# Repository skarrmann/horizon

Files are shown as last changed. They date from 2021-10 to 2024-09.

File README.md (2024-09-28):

# Horizon Keyboard

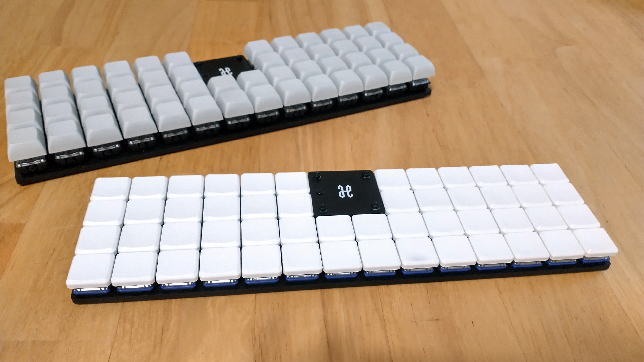
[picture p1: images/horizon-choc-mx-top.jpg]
Horizon Choc + MX complete build top photo


Horizon is a 52 key (4x14) ortholinear keyboard, powered by an Arduino Pro Micro.

This keyboard is a grid of 1U keys with no special features: no hotswap, no RGB, no OLED screen, no knobs.

## Project structure

* [`gerbers`](gerbers): Gerber files for PCB manufacturing
* [`graphics`](graphics): Source assets for PCB silkscreen
* [`kicad`](kicad): KiCad project files (schematics and PCB designs)
* [`kicad-libraries`](kicad-libraries): KiCad components and footprints
* [`kicad-plugins`](kicad-plugins): KiCad Pcbnew Python plugins
* [`images`](images): Images for project documentation

## PCBs

Two separate PCB designs are available for MX and Choc keyswitches, with their respective footprints and key spacing (MX: 19mm x 19mm, Choc: 18mm x 17mm).

Each design consists of a main PCB, a top plate to protect the microcontroller, and a bottom plate to protect the bottom components:

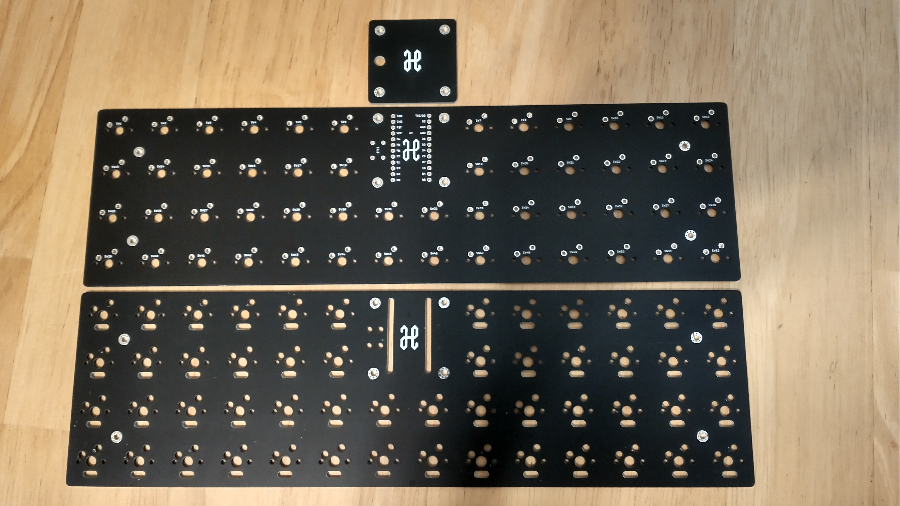
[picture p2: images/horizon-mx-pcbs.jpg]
Horizon MX PCBs photo


The bottom plate is a cutout of all the components exposed through the bottom of the main PCB, and screws *directly* against the main PCB. This nicely guards you and your desk surface from all the pointy through-hole bits, while retaining a low keyboard height:

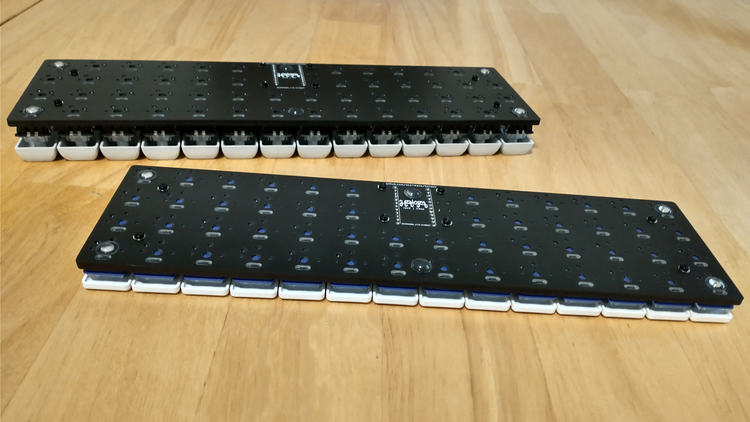
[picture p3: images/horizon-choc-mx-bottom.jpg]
Horizon Choc + MX complete build bottom photo


## KiCad project notes

The bottom and top plates are generated via a custom KiCad 7 Python SWIG plugin [Horizon Board Producer](kicad-plugins/horizon-board-producer-plugin.py).

For the plugin to generate these plate boards, the PCB and its footprints use the following layer convention:

* `F.Adhesive` designates top plate holes and edge cuts.
* `B.Adhesive` designates bottom plate holes and edge cuts.

When the board producer runs, these layers are used as follows:

* On the board and footprints:
    * Graphics on the plate's designated layer will be moved to `Edge.Cuts` when producing that plate.
    * As with all edge cuts, please make sure your graphics are non-overlapping closed shapes.
* On footprints only:
    * Pads of type "SMD Aperture" and shape "Circular/Oval" on the plate's designated layer will be converted to proper NPTH pads.
    * Note only circular/oval shapes are supported for these pads, because they are the only available hole/drill shapes. If you need a fancy plate cutout shape on your footprint, then draw graphics lines on the designated layer.
    * **IMPORTANT**: When adding pads solely for plate cutout purposes, set the technical layer to just the designated plate cutout layers. Leave all other technical layers unchecked.

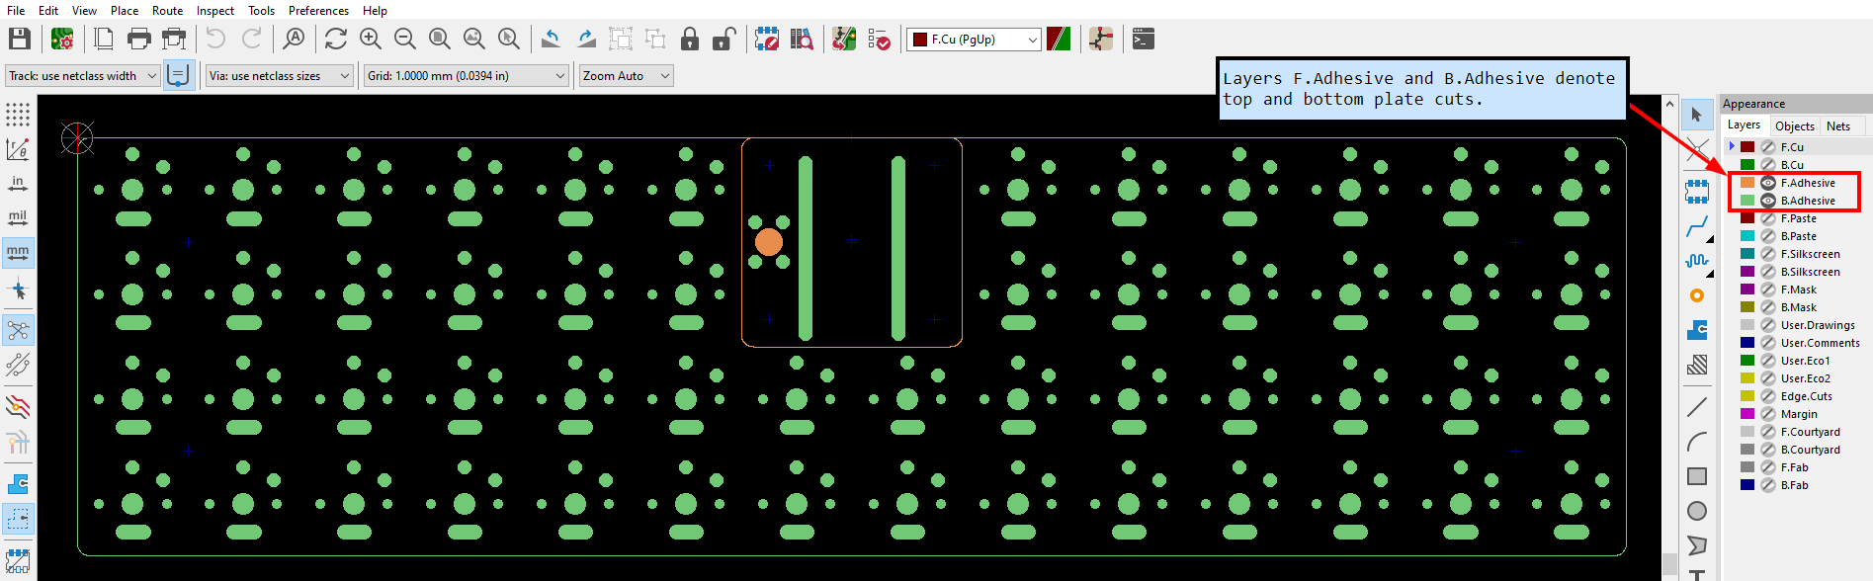
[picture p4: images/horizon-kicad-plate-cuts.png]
Horizon KiCad plate edge cuts

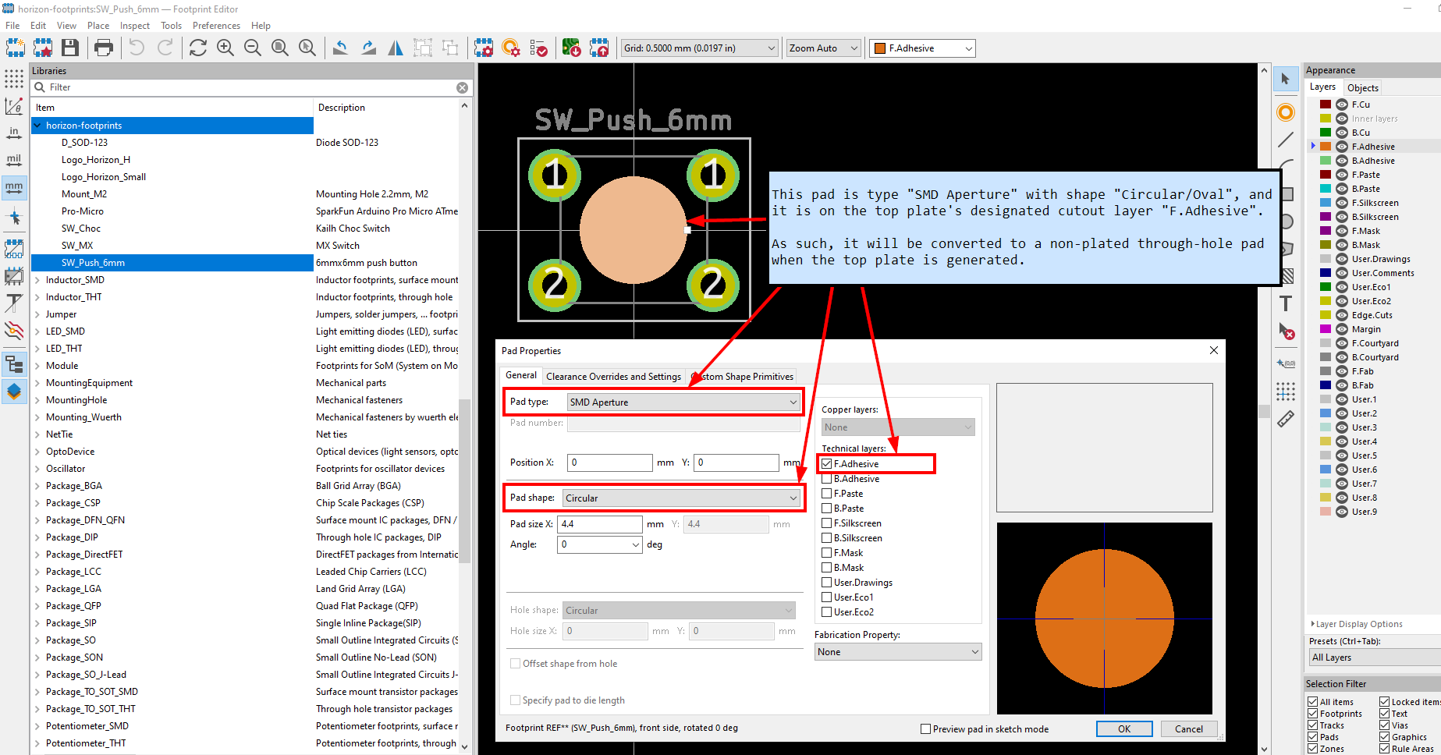
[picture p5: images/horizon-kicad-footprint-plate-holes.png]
Horizon KiCad footprint plate holes


Additionally, the board producer plugin will preserve any in-bounds "H" footprint pads (mounting holes), "LOGO" footprint graphics (custom silkscreen art), and board silkscreen on the plates. Other items which are not needed for plates (e.g., copper tracks and zones) are removed from the plates.

The board producer plugin also generates all the Gerber files for production.

Please note the board producer plugin expects the following folder structure:

* The KiCad PCB file is two folders deep from the project root, e.g., `kicad/[board-version]/[board-name].kicad_pcb`
* When the plugin executes, a folder called `temp` is created in the project root to store any temporary files created.
    * Each time the board producer runs, any existing files in this temporary folder are deleted.

**IMPORTANT:** If you would like to use this plugin and plate edge cuts convention for you own project, please make sure you carefully examine the output Gerber files! The plugin ultimately worked well for my case, but you might need to make adjustments to the plugin to suit your project. And to reduce the chance of being charged extra money by PCB manufacturers, use footprint plate holes instead of edge cuts whenever reasonable to do so.

**IMPORTANT:** This plugin uses `pcbnew.LoadBoard()` to load copies of the PCB, which is [not safely supported in a running instance of KiCad](https://forum.kicad.info/t/the-loadboard-function-is-invalid/31238/9). To avoid project integrity problems this may cause to the running KiCad instance, the plugin forcefully exits KiCad upon execution completion.

## Keyboard firmware

* [QMK](https://github.com/qmk/qmk_firmware/tree/master/keyboards/horizon)
* ZMK
    * Horizon shield definition is in [skarrmann's zmk-config](https://github.com/skarrmann/zmk-config)

## Bill of materials

For PCBs, keyswitches, and keycaps, get parts depending on your desired keyswitch type.

Part | Purpose | Quantity | Notes
---- | ------- | -------- | ---------
Main PCB  | circuit board | 1 | Send Gerber zip files to [JLCPCB](https://jlcpcb.com/).
Top plate PCB  | protects microcontroller | 1 |
Bottom plate PCB  | protects bottom pins and components | 1 |
Arduino Pro Micro | Microcontroller board | 1 | Or use another Pro Micro compatible dev board with same dimensions (confirmed Elite-C V4, nice!nano 2.0, SuperMini nRF52840, and Adafruit KB2040 fit)
6x6mm DIP 4-pin tactile switch | Reset button | 1 |
1N4148 SOD-123 | Diodes for keyboard row-column matrix | 52 |
Keyswitches |  | 52 | PCB mount (5 pin) switches recommended. For MX, any switches should work. For Choc, get Choc V1 switches.
Keycaps |  | 52 | For MX, any keycaps should work. For Choc, get those which fit Choc V1 18mm x 17mm
M2 6mm screws | Secure main PCB and plate PCBs | 8 |
M2 nuts | Secure main PCB and plate PCBs | 8 |
M2 8mm male-female standoffs | Raise top plate PCB above microcontroller | 4 |
2mm tall rubber bumpons | Raise board above desk surface and provide skid resitance | 6 |

I recommend using sockets for the Pro Micro. For socketing options, refer to [40% Keyboards' sockets article](https://www.40percent.club/2018/03/sockets.html).

M2 standoff height requirements are dependent on the seated microcontroller height. An M2 spacer set should give you enough options. I recommend getting a reset button ~2mm taller than the M2 standoffs so the button is level with the top plate.

If using a bluetooth Pro Micro compatible dev board, then power it with battery size 301230. On the dev board, use sockets which provide at least 3mm clearance for the battery to fit underneath. Cut the battery wires so they are just long enough to poke through the B-/B+ pins from the underside of the dev board. Solder the battery's black wire to the B- pin, and the red wire to the B+ pin. Use a piece of Kapton or electrical tape to secure the battery to the dev board. When done, the dev board should look something like this:

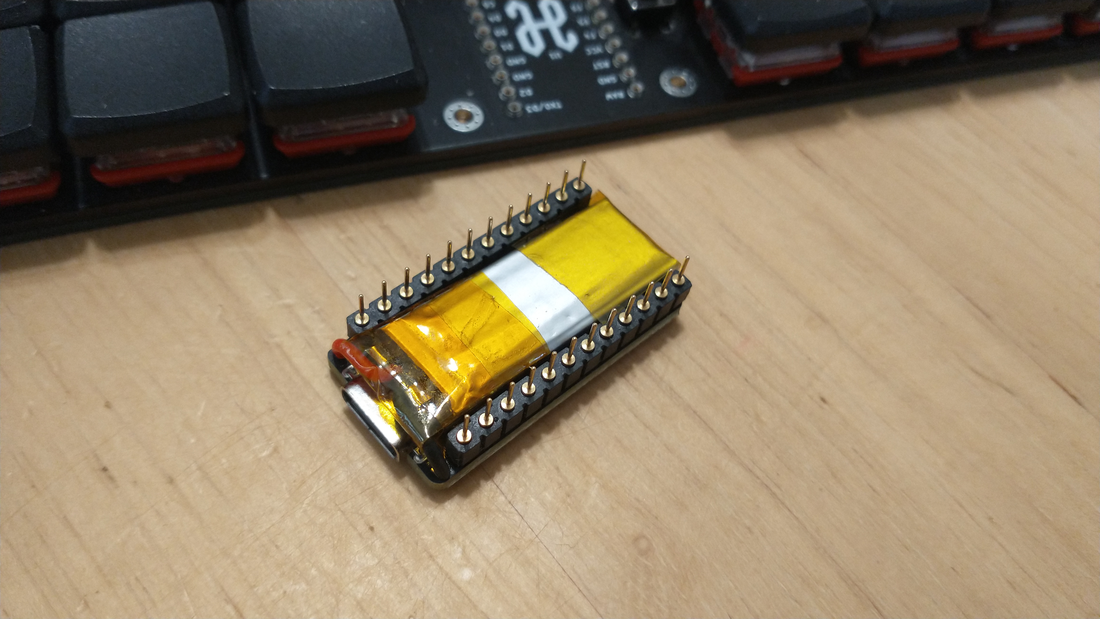
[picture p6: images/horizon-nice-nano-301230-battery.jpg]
nice!nano with 301230 battery underneath, soldered to the B+/B- pins


Horizon does not use a power switch or battery connector, so no other parts are needed when using a bluetooth Pro Micro compatible board. Since there is no physical power switch, refer to [ZMK's power management configuration](https://zmk.dev/docs/config/power) to manage power through firmware features.

## PCB manufacturing settings

These are the manufacturing settings I used when ordering from JLCPCB:

* **Base Material**: FR4
* **Layers**: 2
* **Dimensions**: (whatever the gerber file specifies)
* **PCB Qty**: 5
* **Different Design**: 1
* **Delivery Format**: Single PCB
* **PCB Thickness**: 1.6
* **PCB Color**: Black
* **Silkscreen**: White
* **Surface Finish**: LeadFree HASL-RoHS
* **Outer Copper Weight**: 1 oz
* **Gold Fingers**: No
* **Confirm Production File**: No
* **Flying Probe Test**: Fully Test
* **Castellated Holes**: No
* **Remove Order Number**: Specify a location

**IMPORTANT:** All PCBs have ["JLCJLCJLCJLC" silkscreen text](https://support.jlcpcb.com/article/28-how-to-remove-order-number-from-your-pcb) underneath the Pro Micro footprint. If you want to remove the order number from the boards or you want to print the PCBs with another manufacturer, then I recommend removing this silkscreen text from the `.kicad_pcb` file, and then re-run the Horizon Board Producer plugin to create the updated Gerber files.

## Build tips

* The microcontroller needs to be soldered with the components facing down.
* The main PCB uses a ground plane, so ground pads are more stubborn to solder. Make sure your soldering tip has good surface area coverage across the pad and component leg. If your soldering iron supports it, turning up the temperature a bit can help too.
* Before soldering the keyswitches, make sure they are perfectly straight and fully inserted into the PCB. Put the keycaps on the inserted keyswitches, and give a thorough visual inspection for any spacing or height irregularities between the keycaps. For MX builds, Gateron switches in particular have thicker PCB-mount pins - push these keyswitches in hard to make sure they are fully inserted!
* To get a perfect fit between the main PCB and bottom plate, keep your soldering tidy! Clean any excess solder/flux which falls outside the bounds of the bottom plate cutouts.
* Attaching the main PCB and the bottom plate requires a very steady hand. The approach that worked best for me was using narrow tweezers to grip the edges of the hex nut against the main PCB, while driving in the screw from the bottom plate.
* The top plate is a very tight fit. If the inner keycaps rub against it, first ensure the top plate is perfectly centered. To center it, slide a thin piece of cardstock in-and-out between the inner keycaps and the top plate on all sides. If that does not resolve the keycaps rubbing, then remove the top plate, sand its edges a bit, and try again.

## Revision history

* **Rev1** (2021-07-30 - not publicly released):
    * PCB: Experimental prototype of MX board.
    * Schematic: Wire as 42 key 7x6 matrix (original release only had 6 keys on bottom row).
* **Rev2** (2021-09-26)
    * PCB: Create MX and Choc boards with bottom and top plates.
    * Schematic: Wire as 52 key 4x14 matrix.
* **Rev2.1** (2021-10-24)
    * PCB: Slightly improve thermal relief clearance to make soldering ground pads easier.
* **Rev2.2** (2021-10-25)
    * Horizon Board Producer plugin: Now supports converting designated placeholder pads to NPTH pads during plate generation.
    * Footprints: Replace graphics which indicate plate cutouts with placeholder pads which indicate plate NPTH pads.
    * PCB: Gerber files regenerated using updated board producer plugin.
* **Rev2.3** (2022-03-21)
    * Horizon Board Producer plugin: Upgrade to KiCad 6
    * PCB, Schematic: No physical changes. Files upgraded to KiCad 6, and Gerber files regenerated using updated files.
* **Rev2.4** (2023-11-09)
    * Horizon Board Producer plugin: Upgrade to KiCad 7
    * PCB, Schematic: No physical changes. Files upgraded to KiCad 7, and Gerber files regenerated using updated files.

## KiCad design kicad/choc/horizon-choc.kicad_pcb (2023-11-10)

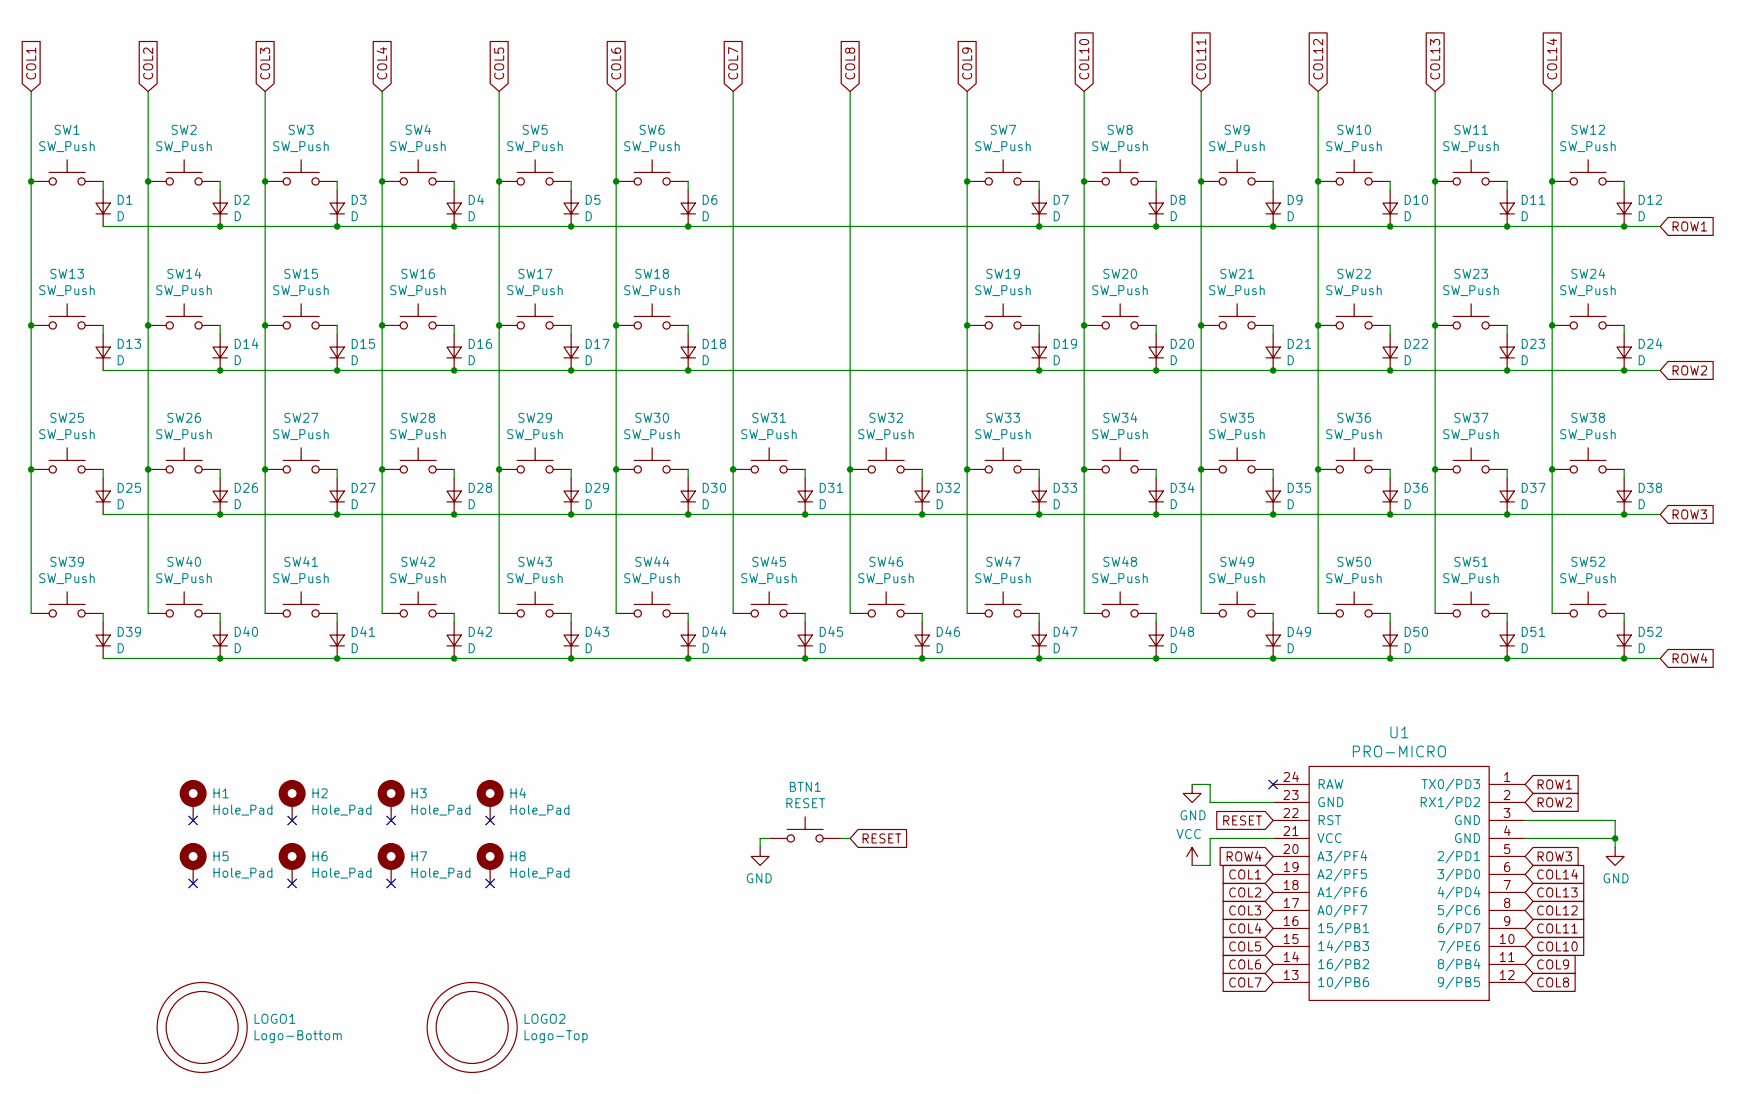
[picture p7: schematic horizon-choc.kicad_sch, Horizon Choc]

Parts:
BTN1: RESET; SW_Push_6mm
D1, D2, D3, D4, D5, D6, D7, D8, D9, D10, D11, D12, D13, D14, D15, D16, D17, D18, D19, D20, D21, D22, D23, D24, D25, D26, D27, D28, D29, D30, D31, D32, D33, D34, D35, D36, D37, D38, D39, D40, D41, D42, D43, D44, D45, D46, D47, D48, D49, D50, D51, D52: D; D_SOD-123
H1, H2, H3, H4, H5, H6, H7, H8: Hole_Pad; Mount_M2
LOGO1: Logo-Bottom; Logo_Horizon_Small
LOGO2: Logo-Top; Logo_Horizon_H
SW1, SW2, SW3, SW4, SW5, SW6, SW7, SW8, SW9, SW10, SW11, SW12, SW13, SW14, SW15, SW16, SW17, SW18, SW19, SW20, SW21, SW22, SW23, SW24, SW25, SW26, SW27, SW28, SW29, SW30, SW31, SW32, SW33, SW34, SW35, SW36, SW37, SW38, SW39, SW40, SW41, SW42, SW43, SW44, SW45, SW46, SW47, SW48, SW49, SW50, SW51, SW52: SW_Push; SW_Choc
U1: PRO-MICRO; Pro-Micro

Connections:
COL1: SW1.1, SW13.1, SW25.1, SW39.1, U1.19 (A2/PF5)
COL2: SW2.1, SW14.1, SW26.1, SW40.1, U1.18 (A1/PF6)
COL3: SW3.1, SW15.1, SW27.1, SW41.1, U1.17 (A0/PF7)
COL4: SW4.1, SW16.1, SW28.1, SW42.1, U1.16 (15/PB1)
COL5: SW5.1, SW17.1, SW29.1, SW43.1, U1.15 (14/PB3)
COL6: SW6.1, SW18.1, SW30.1, SW44.1, U1.14 (16/PB2)
COL7: SW31.1, SW45.1, U1.13 (10/PB6)
COL8: SW32.1, SW46.1, U1.12 (9/PB5)
COL9: SW7.1, SW19.1, SW33.1, SW47.1, U1.11 (8/PB4)
COL10: SW8.1, SW20.1, SW34.1, SW48.1, U1.10 (7/PE6)
COL11: SW9.1, SW21.1, SW35.1, SW49.1, U1.9 (6/PD7)
COL12: SW10.1, SW22.1, SW36.1, SW50.1, U1.8 (5/PC6)
COL13: SW11.1, SW23.1, SW37.1, SW51.1, U1.7 (4/PD4)
COL14: SW12.1, SW24.1, SW38.1, SW52.1, U1.6 (3/PD0)
GND: BTN1.2, U1.3 (GND), U1.4 (GND), U1.23 (GND)
unnamed: D1.2 (A), SW1.2
unnamed: D2.2 (A), SW2.2
unnamed: D3.2 (A), SW3.2
unnamed: D4.2 (A), SW4.2
unnamed: D5.2 (A), SW5.2
unnamed: D6.2 (A), SW6.2
unnamed: D7.2 (A), SW7.2
unnamed: D8.2 (A), SW8.2
unnamed: D9.2 (A), SW9.2
unnamed: D10.2 (A), SW10.2
unnamed: D11.2 (A), SW11.2
unnamed: D12.2 (A), SW12.2
unnamed: D13.2 (A), SW13.2
unnamed: D14.2 (A), SW14.2
unnamed: D15.2 (A), SW15.2
unnamed: D16.2 (A), SW16.2
unnamed: D17.2 (A), SW17.2
unnamed: D18.2 (A), SW18.2
unnamed: D19.2 (A), SW19.2
unnamed: D20.2 (A), SW20.2
unnamed: D21.2 (A), SW21.2
unnamed: D22.2 (A), SW22.2
unnamed: D23.2 (A), SW23.2
unnamed: D24.2 (A), SW24.2
unnamed: D25.2 (A), SW25.2
unnamed: D26.2 (A), SW26.2
unnamed: D27.2 (A), SW27.2
unnamed: D28.2 (A), SW28.2
unnamed: D29.2 (A), SW29.2
unnamed: D30.2 (A), SW30.2
unnamed: D31.2 (A), SW31.2
unnamed: D32.2 (A), SW32.2
unnamed: D33.2 (A), SW33.2
unnamed: D34.2 (A), SW34.2
unnamed: D35.2 (A), SW35.2
unnamed: D36.2 (A), SW36.2
unnamed: D37.2 (A), SW37.2
unnamed: D38.2 (A), SW38.2
unnamed: D39.2 (A), SW39.2
unnamed: D40.2 (A), SW40.2
unnamed: D41.2 (A), SW41.2
unnamed: D42.2 (A), SW42.2
unnamed: D43.2 (A), SW43.2
unnamed: D44.2 (A), SW44.2
unnamed: D45.2 (A), SW45.2
unnamed: D46.2 (A), SW46.2
unnamed: D47.2 (A), SW47.2
unnamed: D48.2 (A), SW48.2
unnamed: D49.2 (A), SW49.2
unnamed: D50.2 (A), SW50.2
unnamed: D51.2 (A), SW51.2
unnamed: D52.2 (A), SW52.2
RESET: BTN1.1, U1.22 (RST)
ROW1: D1.1 (K), D2.1 (K), D3.1 (K), D4.1 (K), D5.1 (K), D6.1 (K), D7.1 (K), D8.1 (K), D9.1 (K), D10.1 (K), D11.1 (K), D12.1 (K), U1.1 (TX0/PD3)
ROW2: D13.1 (K), D14.1 (K), D15.1 (K), D16.1 (K), D17.1 (K), D18.1 (K), D19.1 (K), D20.1 (K), D21.1 (K), D22.1 (K), D23.1 (K), D24.1 (K), U1.2 (RX1/PD2)
ROW3: D25.1 (K), D26.1 (K), D27.1 (K), D28.1 (K), D29.1 (K), D30.1 (K), D31.1 (K), D32.1 (K), D33.1 (K), D34.1 (K), D35.1 (K), D36.1 (K), D37.1 (K), D38.1 (K), U1.5 (2/PD1)
ROW4: D39.1 (K), D40.1 (K), D41.1 (K), D42.1 (K), D43.1 (K), D44.1 (K), D45.1 (K), D46.1 (K), D47.1 (K), D48.1 (K), D49.1 (K), D50.1 (K), D51.1 (K), D52.1 (K), U1.20 (A3/PF4)

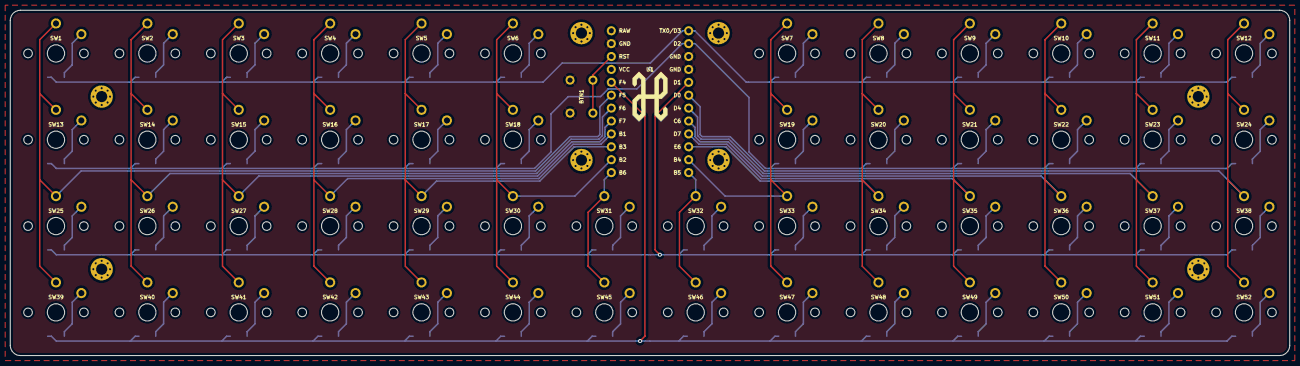
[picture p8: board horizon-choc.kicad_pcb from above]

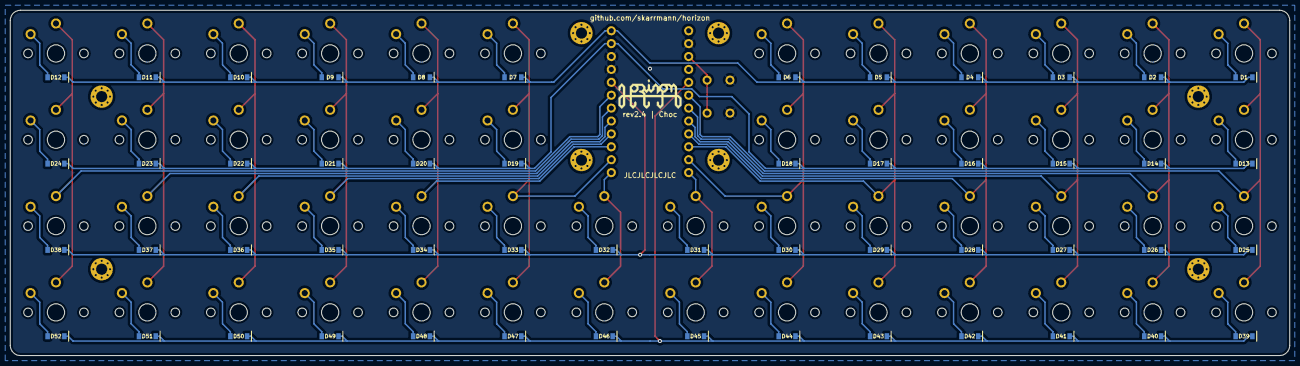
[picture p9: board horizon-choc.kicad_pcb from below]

Board: 2 copper layers, 252.0 x 68.0 mm, 116 parts (53 on the bottom side), 72 nets.

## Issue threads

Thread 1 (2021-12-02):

How to generate cutout graphics for custom components?

zzeneg, 2021-12-02:
Hi,

I really like your approach with the bottom plate as a "case" and I'm trying to implement the same for my custom keyboard. As far as I understand you have custom footprints for the components you use which already have graphics on `Adhes` layers. I'm building a regular keyboard so I can't just use your footprints as I need 1.5U, 2U keys, stabilizers, etc. How did you add the graphics? Is it totally manual or is there some way to automate it?

skarrmann, 2021-12-03:
Hello @zzeneg! Thank you for your question. I will update the readme with more details about how to create footprints that work with this board producer plugin, but for now hopefully this answer helps. Please let me know if you need any more details.

Your understanding of the footprints and the `Adhes` layers is correct.

I manually created the footprints. It takes a little bit of work. You might have already seen it, but there are some brief notes in the readme about how these footprints are configured: https://github.com/skarrmann/horizon#kicad-project-notes

Basically you need to create placeholder circular/oval SMD pads on the footprint to indicate the plate cutouts.

Here are some practices I followed when creating the keyswitch footprints with cutouts:

* For the mounting hole pads (like for the a keyswitch's center mounting hole and the two PCB mounting pins), copy the original pad and then change these settings:
    * Pad type: SMD
    * Copper: None
    * Size X: [use original pad size]
    * Technical layers: *disable all layers* except this one
        * B.Adhes ("B" is for bottom plate, "F" is for top plate)

* For the through-hole solder pads (like for the keyswitch's two pins), it's similar with a couple of adjustments. Copy the original pad and then change these settings:
    * Pad number: [set this to empty]
    * Pad type: SMD
    * Size X: [increase original pad size by 0.4mm - this extra space is accounts for possible solder/flux overflow]
    * Technical layers: *disable all layers* except this one
        * B.Adhes ("B" is for bottom plate, "F" is for top plate)

If you need cutout shapes other than a circles/ovals, you can draw graphics directly on the footprint on the `B.Adhes` and `F.Adhes` layers, using KiCad's graphic line / graphic arc tools. However, if you have a lot of cutouts drawn with graphics way, PCB manufacturers might charge extra for the plates due to milling time.

zzeneg, 2021-12-06:
Awesome, thank you for such detailed instructions, as a total newbie in kicad I really appreciate it :)

Closed 2021-12-06.

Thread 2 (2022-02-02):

Numrow version

maximilienGilet, 2022-02-02:
Hi, I really like this keyboard design (especially the ultra-thin double pcb idea) but I would LOVE a numrow version.

Do you plan to do one ?

Thanks in advance

Gauvainb, 2022-02-02:
I second this. A numwow variant would make it a killer.

skarrmann, 2022-02-02:
Thank you both for your interest!

I have considered making a 5-row version of the Horizon. I will look into it this weekend.

With the additional row, there are two layout options for the center keys:

```
A. 64 keys (4 center keys)
oooooo  oooooo
oooooo  oooooo
oooooo  oooooo
oooooooooooooo
oooooooooooooo

B. 66 keys (6 center keys)
oooooo  oooooo
oooooo  oooooo
oooooooooooooo
oooooooooooooo
oooooooooooooo
```

I prefer option B. Do you have a preference?

Gauvainb, 2022-02-02:
Hi @skarrmann, thanks for your swift reply !
I'd opt for option B as well, but only speaking for myself here.

maximilienGilet, 2022-02-02:
Thanks for the quick reply !

I would also prefer option B even if the Horizon64 name would be epic haha

Do you think option A would allow a tiny battery for a BLE board ?

skarrmann, 2022-02-02:
Great, thanks for your replies @Gauvainb and @maximilienGilet.I'll start with the 66 key approach then.

@maximilienGilet With the 64 key option, the extra space would allow for a larger LiPo battery. However, the 301230 size (3.0mm height x 12mm width x 30mm length) LiPo battery would work for the 66 layout key too! [Here's a photo showing this battery under a nice!nano](https://photos.app.goo.gl/HzBFCZwWxUVowQeq8).

skarrmann, 2022-02-06:
The the 5-row version of Horizon is almost done! Introducing Morizon: https://github.com/skarrmann/morizon

The PCB designs for both MX and Choc versions are complete. And the QMK firmware should be all set too.

I plan on reviewing the PCBs one more time just to make sure everything is correct. And then later in the week, I will probably submit one of the boards to JLCPCB for printing (most likely the MX version - I have some spare switches to use).

@maximilienGilet @Gauvainb If you have a chance, could you please check the Morizon repository and see if the PCB and Gerber files look good to you? Thank you!

maximilienGilet, 2022-02-06:
Epic !

Sadly I know nothing about pcb design so I will only help with build photos

If the rev1 is working as intended I will order a choc version and build one with a nice!nano and battery

Gauvainb, 2022-02-08:
>

Brilliant, I will have a look hoping my very limited PCB design skills can help !
Thanks for your work !

skarrmann, 2022-02-09:
I finished my review of the PCBs, and everything looks correct. @Gauvainb Thank you for taking a look, and let me know if you notice any issues!

Tomorrow night (unless an issue is found), I will submit the MX Morizon PCBs to JLCPCB for printing.

skarrmann, 2022-02-10:
[MX Morizon PCBs have been ordered from JLCPCB](https://i.imgur.com/1l9SuLv.png).

JLCPCB approved the designs just a few minutes after ordering. There were no extra costs either :)

If you would like to order PCBs and are eager to build the keyboard, then I am fairly confident the design is ready for your use now. But if you want to be cautious, I will confirm how everything goes after I finish the keyboard build.

It will take about two weeks for the PCBs to arrive. I will let you know when I receive them.

Gauvainb, 2022-02-10:
Excellent, thanks again for your work on this ! I tend to always be on the cautious side after letdowns with different designs...But this one being a derivative of the original horizon I see no reason why it wouldn't work.

Plan is to try and build a choc slim one with nice!nano and small battery for a fully BT work setup!

skarrmann, 2022-03-02:
The Morizon MX PCBs arrived from JLCPCB today. They look great!

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

I will build it and test it by this weekend. I will keep you posted!

maximilienGilet, 2022-03-03:
Looks so damn good !

Thank you for your dedication

Gauvainb, 2022-03-03:
Can't wait to see the results !

skarrmann, 2022-03-05:
The Morizon MX build is complete, and everything works perfectly with the QMK keyboard definition 😃.

Here are some photos of the finished product:

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

Tomorrow, I will submit the PR for the QMK firmware, and write an intro post on /r/olkb.

I would love to see your finished builds too. If you could take a photo of a complete Morizon Choc build and allow me to show it on the repo, I would greatly appreciate it.

Thank you both for your interest!

maximilienGilet, 2022-03-07:
Epic ! I will coordinate with @Gauvainb for Choc builds with a battery and a nice!nano

thanks a lot

Closed 2022-03-05.

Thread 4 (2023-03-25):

question: Power switch if using ZMK/nice!nano

mangkoran, 2023-03-25:
First of all, thank you for your amazing work! I have been daily driving morizon and it's an endgame board for me (ortho, 5x12, Pro-Micro, lower profile than contra. Open-sourced Preonic in a nutshell).

I would like to ask a question regarding ZMK/nice!nano. I saw that you provided ZMK config for horizon/morizon, which implies you have used them with nice!nano. As I couldn't see any Power switch pad on the board, are the boards will always turned on if I decided to use nice!nano? Although ZMK does have sleep features..

skarrmann, 2023-03-25:
Hello! I am very glad you are enjoying Morizon.

The current Horizon/Morizon PCB designs do not have a footprint for a power switch. I've used the nice!nano always turned on, and it provided battery life of about 2 weeks of daily use. Personally, I prefer wired keyboards, which is why I did not add wireless-only features to the PCB.

A power switch would be nice for travel and when storing the keyboard. Adding a power switch footprint to the PCB, to the right of the microcontroller board, opposite the reset button, could be a nice design addition. But it's more than I wanted for this simple low profile board design.

Let me know if you have any questions!

mangkoran, 2023-03-26:
Thank you for sharing! I am very impressed on how nice!nano managed to have enormous battery life (well might be due to ZMK deep sleep but nonetheless it is with always-turned-on power).

 I will close this "issue" ticket then.

Closed 2023-03-26.

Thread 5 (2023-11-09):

Python plugin doesn't work in KiCad 7

Pe8er, 2023-11-09:
Hi!

[I'm making an attempt](https://github.com/Pe8er/horizon-mini/tree/main/kicad/choc) to reduce the size of your fantastic design to 10 columns. However, the board producer plugin throws the following error in KiCad 7:

```
Traceback (most recent call last):

File "/Users/pe8er/Documents/KiCad/7.0/3rdparty/plugins/horizon-board-producer-plugin.py", line 20, in Run
HorizonBoardProducerPlugin.produce()

File "/Users/pe8er/Documents/KiCad/7.0/3rdparty/plugins/horizon-board-producer-plugin.py", line 248, in produce
HorizonBoardProducerPlugin.__create_gerbers(pcb, gerber_output_path)

File "/Users/pe8er/Documents/KiCad/7.0/3rdparty/plugins/horizon-board-producer-plugin.py", line 41, in __create_gerbers
plot_options.SetExcludeEdgeLayer(True)

AttributeError: 'PCB_PLOT_PARAMS' object has no attribute 'SetExcludeEdgeLayer'
```

Any chance you could fix it please? Thanks a ton!

skarrmann, 2023-11-09:
Hello!

Yes, I will try migrating the board generator plugin code to KiCad 7 within the next couple days. It was last migrated to KiCad 6, so it needs to be updated again.

I will let you know how it goes.

Pe8er, 2023-11-09:
Thanks and good luck!

skarrmann, 2023-11-10:
Thanks!

Can you please try running this updated plugin code in KiCad 7? https://github.com/skarrmann/horizon/blob/ec8f4e240b31b75347d11e4e73a34dd3b1617870/kicad-plugins/horizon-board-producer-plugin.py

I confirmed the update works for me on KiCad 7.0.9. Please note KiCad will forcefully close after the plugin successfully runs. You should see this message if the plugin successfully generated the fabrication files:

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

Let me know if this updated code works for you. If it's good, I will merge this update into the main project. Thank you!

Pe8er, 2023-11-10:
It works on KiCad 7.0.8 on Mac, and the script kills KiCad at the end. I reviewed the gerbers as best as I could, they looked fine so I just submitted an order 😀 Thank you so much!

skarrmann, 2023-11-10:
Great! Thank you for testing this update.

Good luck with your Horizon Mini, and I'd love to hear how the build goes.

Pe8er, 2023-11-11:
I will let you know for sure, hopefully it works 🤞

Pe8er, 2024-01-23:
@skarrmann Hey! It is alive! 😀

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

There is just one remaining issue: it seems like the battery is not charging. I don't know if the battery is broken or is it something with my soldering, or maybe ZMK. I'm off to get help on ZMK Discord.

Closed 2023-11-10.

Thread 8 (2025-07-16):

Case

222Phoenix, 2025-07-16:
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

Not an issue, just an FYI that a chopstick box is just about perfect for the board.

Closed 2025-07-16.

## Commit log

2021-08-09 Fix relative path of gerber file output
    [horizon.kicad_pcb]
2021-08-22 Begin revision 2
    [horizon.kicad_pcb, horizon.sch]
2021-08-24 Create bottom plate board. Begin laying out Choc switch board. Clean up footprints and remove unused ones
    [horizon-bottom-plate.kicad_pcb, horizon-choc.kicad_pcb, horizon.kicad_pcb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]
2021-08-25 Adjust center component layout for MX and Choc consistency.
    [horizon-bottom-plate.kicad_pcb, horizon-choc.kicad_pcb, horizon-choc.sch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]
2021-08-26 Route traces on choc version
    [horizon-choc.kicad_pcb, horizon-choc.sch]
2021-08-28 Route Choc board with diodes in center
    [horizon-choc.kicad_pcb]
2021-09-03 Use 50 key layout on MX version
    [horizon-choc.kicad_pcb, horizon.kicad_pcb, horizon.sch]
2021-09-04 Clean up MX version before overhaul
    [horizon.kicad_pcb, horizon.sch]
2021-09-06 Implement battery on Choc version, plus bottom and top PCBs
    [horizon-choc-bottom-plate.kicad_pcb, horizon-choc-top-cover.kicad_pcb, horizon-choc.kicad_pcb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]
2021-09-08 Use 50-key layout
    [horizon-choc-bottom-plate.kicad_pcb, horizon-choc-top-cover.kicad_pcb, horizon-choc.kicad_pcb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]
2021-09-12 Layout MX PCB
    [horizon-choc-bottom-plate.kicad_pcb, horizon-choc-top-cover.kicad_pcb, horizon-choc.kicad_pcb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]
2021-09-13 Mark bottom plate cutout on footprint adhesive layer. Begin writing bottom plate generation script
    [horizon-bottom-plate.kicad_pcb, horizon-choc-bottom-plate.kicad_pcb, horizon-choc-top-cover.kicad_pcb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]
2021-09-13 Distinguish between top and bottom cuts with front/back adhesive layers
    [horizon.kicad_pcb]
2021-09-13 Mark top and bottom plate border edge cuts on boards with adhesive layers
    [horizon-choc-top-cover.kicad_pcb, horizon-choc.kicad_pcb, horizon-top-cover.kicad_pcb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]
2021-09-18 Update plate outlines. Remove battery from Choc design for now
    [horizon-choc.kicad_pcb, horizon-choc.sch]
2021-09-19 Clean up plate cuts, update MX board with battery removed
    [horizon-B_Cu.gbl, horizon-B_Mask.gbs, horizon-B_SilkS.gbo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]
2021-09-20 Create board producer script to generate plates, gerbers, and drill files
    [horizon-choc-B_Cu.gbl, horizon-choc-B_Mask.gbs, horizon-choc-B_SilkS.gbo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]
2021-09-20 Write usage instructions for board producer script
    [horizon-mx-B_Cu.gbl, horizon-mx-B_Mask.gbs, horizon-mx-B_SilkS.gbo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]
2021-09-21 Convert board generator script into KiCAD PcbNew plugin
    [horizon-mx-B_Cu.gbl, horizon-mx-B_Mask.gbs, horizon-mx-B_SilkS.gbo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]
2021-09-25 Preserve logos on plate PCBs
    [horizon-choc-B_Cu.gbl, horizon-choc-B_Mask.gbs, horizon-choc-B_SilkS.gbo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]
2021-09-25 Remove unused footprints and other files. Update readme. Prepare for production!
    [horizon-choc-B_Cu.gbl, horizon-choc-B_Mask.gbs, horizon-choc-B_SilkS.gbo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]
2021-09-25 Remove generated files
    [horizon-choc-B_Cu.gbl, horizon-choc-B_Mask.gbs, horizon-choc-B_SilkS.gbo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]
2021-09-25 Only output gerber zip files in gerbers folder, and put all other production files in gitignored temp folder
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2021-10-09 Fix KiCAD plugin URL in readme
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2021-10-13 Add title block to schematic and PCB files
    [horizon-choc.kicad_pcb, horizon-choc.sch, horizon-mx.kicad_pcb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]
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2021-10-16 Fix JLCPCB Gerber preview note
2021-10-16 Change PCB design file page size to A4
    [horizon-choc.kicad_pcb, horizon-mx.kicad_pcb]
2021-10-21 Use relative paths for KiCad libraries. Fix name case on push button footprint
    [horizon-choc.kicad_pcb, horizon-mx.kicad_pcb]
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2021-10-24 Add notes about using LiPo battery, and clarify pro micro board support)
    [horizon-horus.kicad_pcb, horizon-horus.sch]
2021-10-24 PCB revision 2.1, document revisions
    [horizon-choc.kicad_pcb, horizon-choc.sch, horizon-horus.kicad_pcb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]
2021-10-24 Format revision history
    [horizon-choc.kicad_pcb, horizon-mx.kicad_pcb]
2021-10-26 Rev 2.2 - Update board producer to support footprint NPTH creation for plates
    [horizon-choc.kicad_pcb, horizon-mx.kicad_pcb]
2021-10-26 Non-functional change: Clean up internal order of MX switch footprint pads
    [horizon-mx.kicad_pcb]
2021-10-26 Update board producer to use oval holes drill mode - use alternate drill mode for JLCPCB (https://support.jlcpcb.com/article/149-how-to-generate-gerber-and-drill-files-in-kicad)
2021-10-27 Clean up board producer temp path to ensure stale files are not included in Gerber zip
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2022-02-05 Experiment with KiCad 6 migration (plugin currently fails)
    [horizon-choc.kicad_pcb, horizon-choc.kicad_sch]
2022-03-19 Resave Choc board with updated library footprints
    [horizon-choc.kicad_pcb]
2022-03-20 Create functional plugin which creates new boards (not copies of the main) for the plates
2022-03-21 Get the plugin working with the modify existing board copy approach. Currently-opened project is still mutated as unwanted side effect
2022-03-21 Handle board copy with file system. Show complete dialog when plugin finishes
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2022-03-21 Update projects to KiCad 6 and regenerate gerbers
    [horizon-choc.kicad_pcb, horizon-mx.kicad_pcb, horizon-mx.kicad_sch]
2022-03-21 Upgrade revision to 2.3. Remove KiCad 5 files
    [horizon-choc.kicad_pcb, horizon-choc.kicad_sch, horizon-choc.sch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]
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2022-03-21 Use KiCad 6 symbol library format
    [horizon-choc.kicad_sch, horizon-mx.kicad_sch]
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2023-11-10 Upgrade plugin and project files to KiCad 7
    [horizon-choc.kicad_pcb, horizon-choc.kicad_sch, horizon-mx.kicad_pcb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]
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
